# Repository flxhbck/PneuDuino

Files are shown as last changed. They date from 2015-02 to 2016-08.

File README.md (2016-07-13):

# PneuDuino

Pneuduino is a toolkit for controlling air flow and pressure to design robots that are soft, furniture that is adaptive, clothing that is intelligent, art pieces that are breathing, and many more things.

Disclaimer:
This toolkit is currently designed for workshops that we give. We are working on a more stable version for personal use. In the meantime, you are welcome to use what you find here - but be aware that is a work in progress.

For more information visit http://pneuduino.org/toolkit/

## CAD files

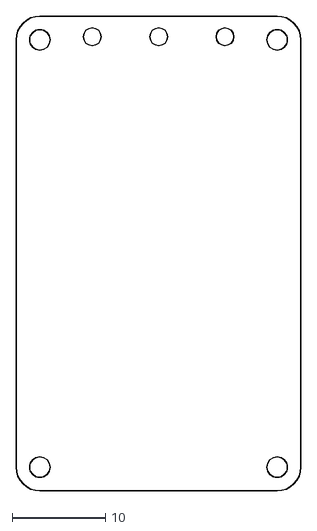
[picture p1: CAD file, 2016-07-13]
v.2/Pneumatic/pneu-slave-outline.dxf
30.5 x 50.8

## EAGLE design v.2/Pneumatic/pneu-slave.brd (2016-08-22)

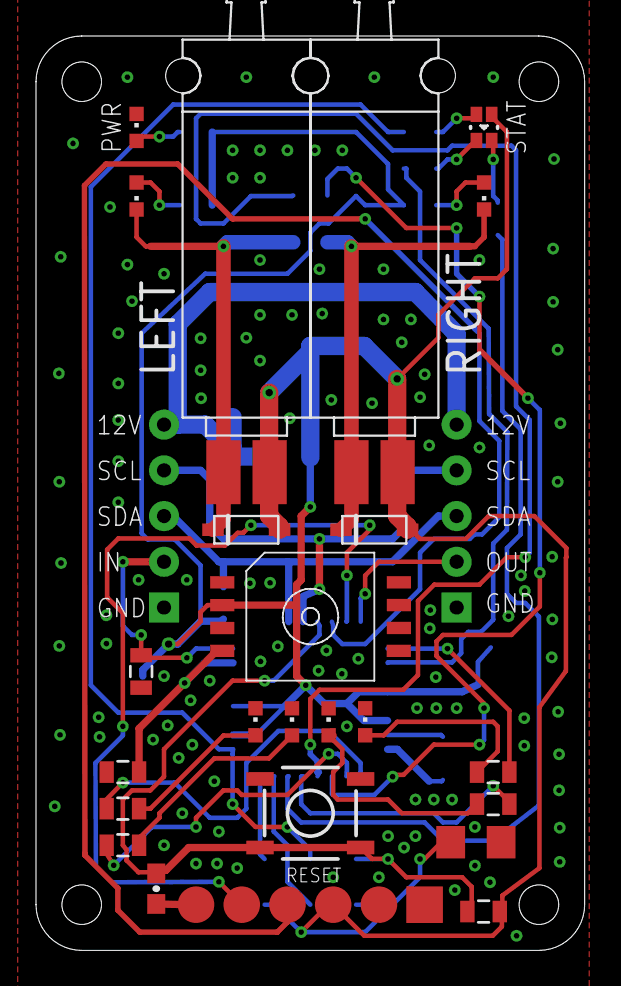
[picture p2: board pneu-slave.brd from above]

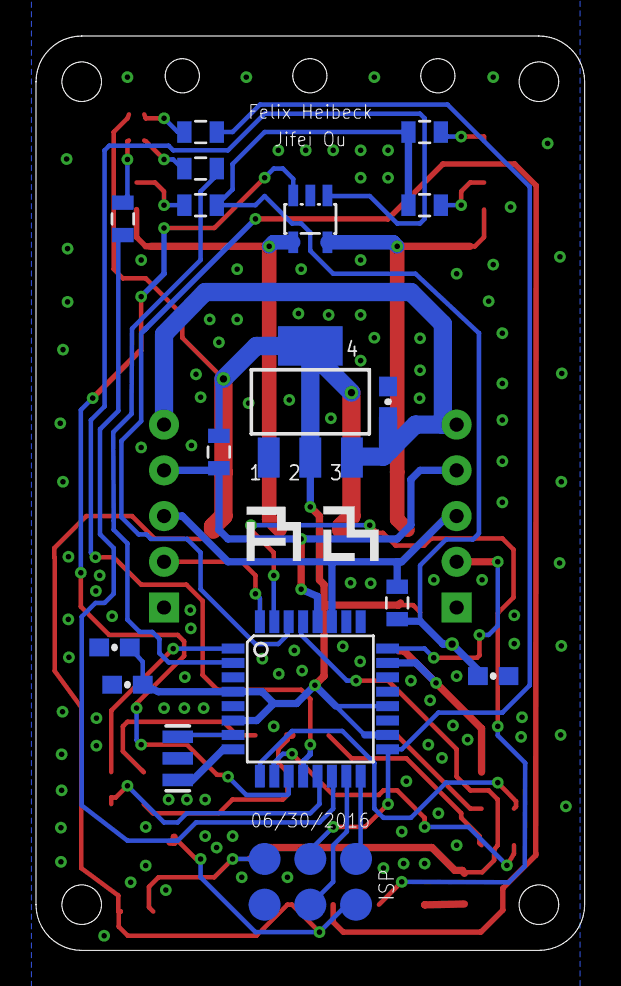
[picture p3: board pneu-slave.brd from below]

Board: 2 copper layers, 30.5 x 50.8 mm, 42 parts (17 on the bottom side), 37 nets.

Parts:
C1, C2, C5, C8, C10: 0.1uF; 0603-CAP
C4: 22uF; 1206
C7: 470pF; 0805
D1, D2: SOD-123
LED_PR1, LED_PR2, LED_PR3, LED_PR4: WHITE; CHIPLED_0603
LED_PWR: RED; CHIPLED_0603
LED_STATUS: LTST-C19FD1WT; LTST
LED_V1, LED_V2: WHITE; CHIPLED_0603
Q1: 16Mhz; RESONATOR-SMD
R1, R2, R4, R7, R8, R9, R10, R11, R12, R13: 1k; 0805
R3: 10K; 0805
R5, R6: 4.7k; 0805
R14: 10k; 0805
S1: TAC_SWITCHSMD; TACTILE-SWITCH-SMD
U0: ATMEGA328; TQFP32-08
U1: NCP1117-5; LINEAR_SOT223
U2: MPXHZ6400
U3: QS5K2; SOT23-5L
U$10: ISP_POGO; POGO_ISP
U$11: S070V-2VALVE; S070C-2
U$12: FTDI_POGO
U$23, U$24: 1X05; 1X05_TIGHT

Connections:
+5V: C2.1, C4.1, C8.1, C10.1, D1.C, D2.C, LED_STATUS.+, R2.2, R3.1, R5.1, R6.2, R8.2, R11.2, U0.4, U0.6, U0.18, U0.20, U1.2, U1.4, U2.2, U$10.2, U$11.1-2, U$11.2-2, U$12.4
A0/PRESSURE: C7.2, U0.23, U2.4
D2/OUT: U0.32, U$23.P$4
D3: R1.2, U0.1
D4: R9.2, U0.2
D5: R7.2, U0.9
D6: R4.2, U0.10
D7: U0.11, U3.3
D8: U0.12, U3.1
D9: R10.2, U0.13
D10: R12.2, U0.14
DTR: C5.2, U$12.1
GND: C1.2, C2.2, C4.2, C7.1, C8.2, C10.2, LED_PR1.C, LED_PR2.C, LED_PR3.C, LED_PR4.C, LED_PWR.C, Q1.2, R14.1, S1.1, S1.2, U0.3, U0.5, U0.21, U1.1, U2.3, U3.2, U$10.6, U$12.5, U$12.6, U$23.P$5, U$24.P$5
IN_PORT: R14.2, U0.24, U$24.P$4
M1_VGND: D1.A, LED_V2.C, U3.4, U$11.2-1
M2_VGND: D2.A, LED_V1.C, U3.5, U$11.1-1
MISO: U0.16, U$10.1
MOSI: U0.15, U$10.4
unnamed: LED_PR2.A, R4.1
unnamed: LED_PR1.A, R7.1
unnamed: Q1.1, U0.8
unnamed: LED_PR4.A, R1.1
unnamed: LED_V2.A, R2.1
unnamed: LED_V1.A, R8.1
unnamed: Q1.3, U0.7
unnamed: LED_PR3.A, R10.1
unnamed: LED_PWR.A, R11.1
unnamed: LED_STATUS.R, R9.1
unnamed: LED_STATUS.G, R12.1
unnamed: LED_STATUS.B, R13.1
RESET: C5.1, R3.2, S1.3, S1.4, U0.29, U$10.5
RX: U0.30, U$12.3
SCK: R13.2, U0.17, U$10.3
SCL: R6.1, U0.28, U$23.P$3, U$24.P$3
SDA: R5.2, U0.27, U$23.P$2, U$24.P$2
TX: U0.31, U$12.2
VIN: C1.1, U1.3, U$23.P$1, U$24.P$1

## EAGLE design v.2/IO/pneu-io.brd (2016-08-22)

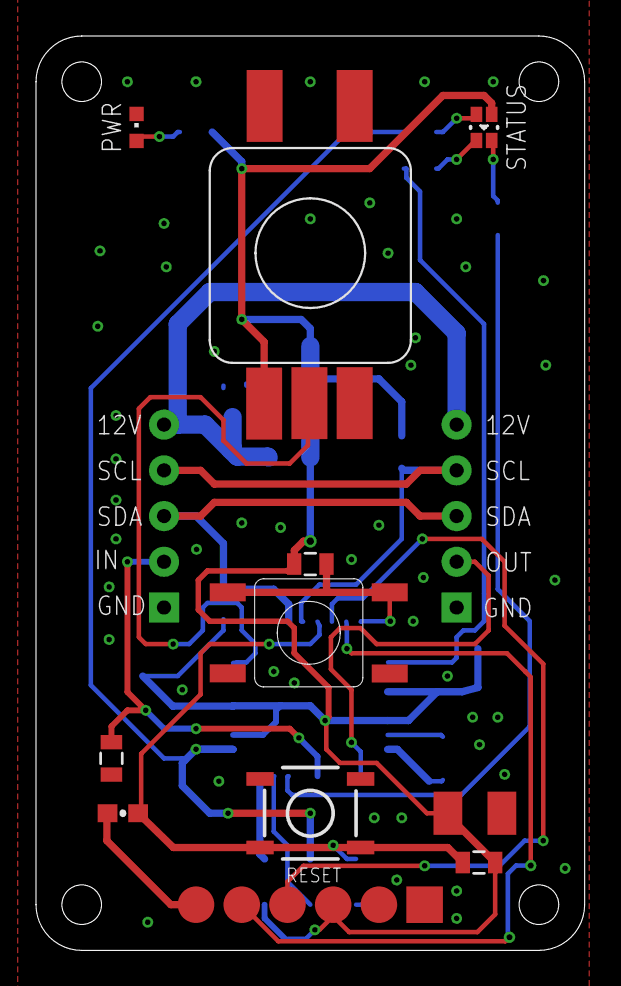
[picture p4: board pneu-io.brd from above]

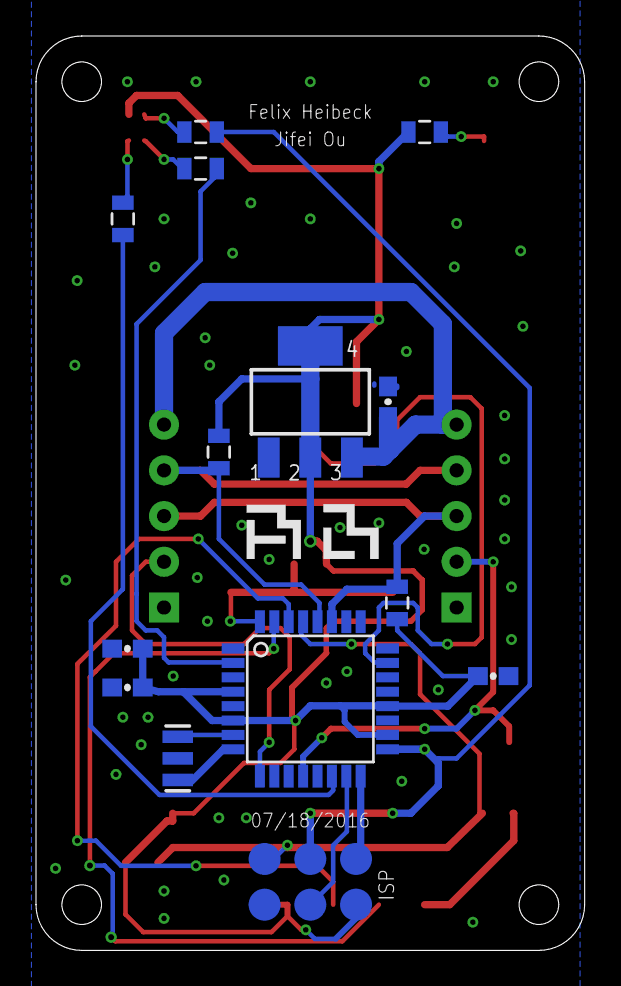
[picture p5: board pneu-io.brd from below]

Board: 2 copper layers, 30.5 x 50.8 mm, 27 parts (14 on the bottom side), 24 nets.

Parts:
C1, C2, C5, C8, C10: 0.1uF; 0603-CAP
C3: 22uF; SMC_B
IC3: ATMEGA328; TQFP32-08
PWR: CHIPLED_0603
Q1: 16Mhz; RESONATOR-SMD
R1, R3: 10K; 0805
R5, R6: 4.7k; 0805
R9, R11, R12, R13: 1k; 0805
R14: 10k; 0805
S1: TAC_SWITCHSMD; TACTILE-SWITCH-SMD
U2: NCP1117-5; LINEAR_SOT223
U$1: RS-014R05; SWITCH-11MM
U$2: PRS11S
U$10: ISP_POGO; POGO_ISP
U$12: FTDI_POGO
U$21: LTST-C19FD1WT; LTST
U$24, U$27: 1X05; 1X05_TIGHT

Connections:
+5V: C2.1, C3.+, C8.1, C10.1, IC3.4, IC3.6, IC3.18, IC3.20, R1.1, R3.1, R5.1, R6.2, R11.2, U2.2, U2.4, U$2.1, U$10.2, U$12.4, U$21.+
A0/POT: IC3.23, U$2.2
D2/BTN: IC3.32, R1.2, U$1.A, U$1.H
D4: IC3.2, R9.2
D5/OUT: IC3.9, U$27.P$4
D8: IC3.12, R14.2, U$24.P$4
D10: IC3.14, R12.2
DTR: C5.2, U$12.1
GND: C1.2, C2.2, C3.-, C8.2, C10.2, IC3.3, IC3.5, IC3.21, PWR.C, Q1.2, R14.1, S1.1, S1.2, U2.1, U$1.B, U$1.D, U$2.3, U$10.6, U$12.5, U$12.6, U$24.P$5, U$27.P$5
MISO: IC3.16, U$10.1
MOSI: IC3.15, U$10.4
unnamed: IC3.8, Q1.1
unnamed: IC3.7, Q1.3
unnamed: PWR.A, R11.1
unnamed: R9.1, U$21.R
unnamed: R12.1, U$21.G
unnamed: R13.1, U$21.B
RESET: C5.1, IC3.29, R3.2, S1.3, S1.4, U$10.5
RX: IC3.30, U$12.3
SCK: IC3.17, R13.2, U$10.3
SCL: IC3.28, R6.1, U$24.P$3, U$27.P$3
SDA: IC3.27, R5.2, U$24.P$2, U$27.P$2
TX: IC3.31, U$12.2
VIN: C1.1, U2.3, U$24.P$1, U$27.P$1

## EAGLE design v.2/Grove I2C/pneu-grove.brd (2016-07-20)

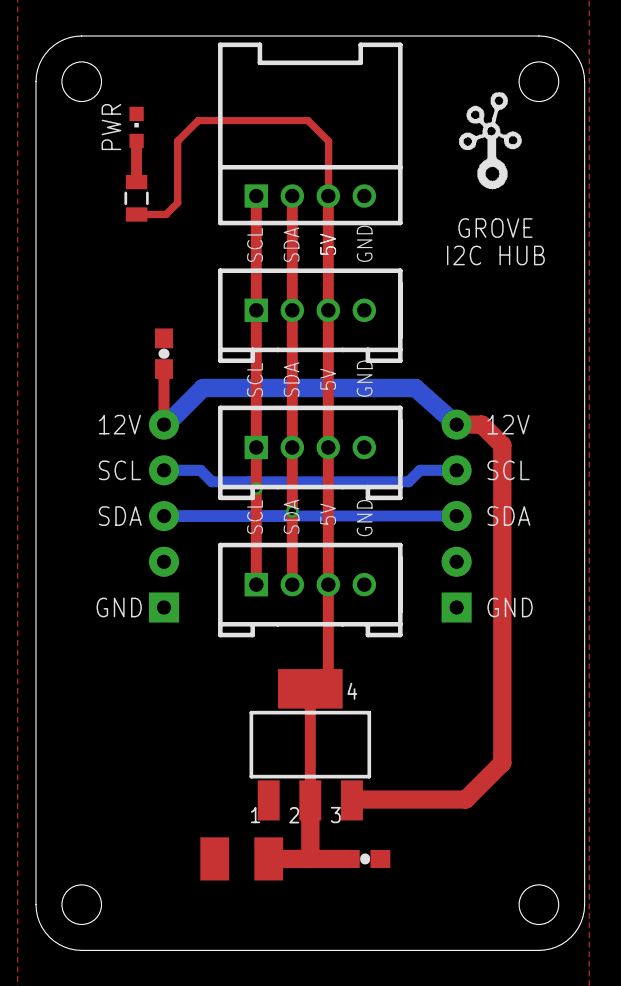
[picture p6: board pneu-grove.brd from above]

Board: 2 copper layers, 30.5 x 50.8 mm, 13 parts (0 on the bottom side), 6 nets.

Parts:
C1, C2: 0.1uF; 0603-CAP
C3: 22uF; SMC_B
J1, J4, J5: TWIG-2.0-DIP; 2.0_1X4
J12: A3; 4P-2.0-90D
PWR: CHIPLED_0603
R11: 1k; 0805
U2: NCP1117-5; LINEAR_SOT223
U$1: TWIGLOGOTWIGLOGO_SMALL; TWIGLOGO_SMALL
U$23, U$24: 1X05; 1X05_TIGHT

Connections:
+5V: C2.1, C3.+, J1.3, J4.3, J5.3, J12.3, R11.2, U2.2, U2.4
GND: C1.2, C2.2, C3.-, J1.4, J4.4, J5.4, J12.4, PWR.C, U2.1, U$23.P$5, U$24.P$5
unnamed: PWR.A, R11.1
SCL: J1.1, J4.1, J5.1, J12.1, U$23.P$3, U$24.P$3
SDA: J1.2, J4.2, J5.2, J12.2, U$23.P$2, U$24.P$2
VIN: C1.1, U2.3, U$23.P$1, U$24.P$1

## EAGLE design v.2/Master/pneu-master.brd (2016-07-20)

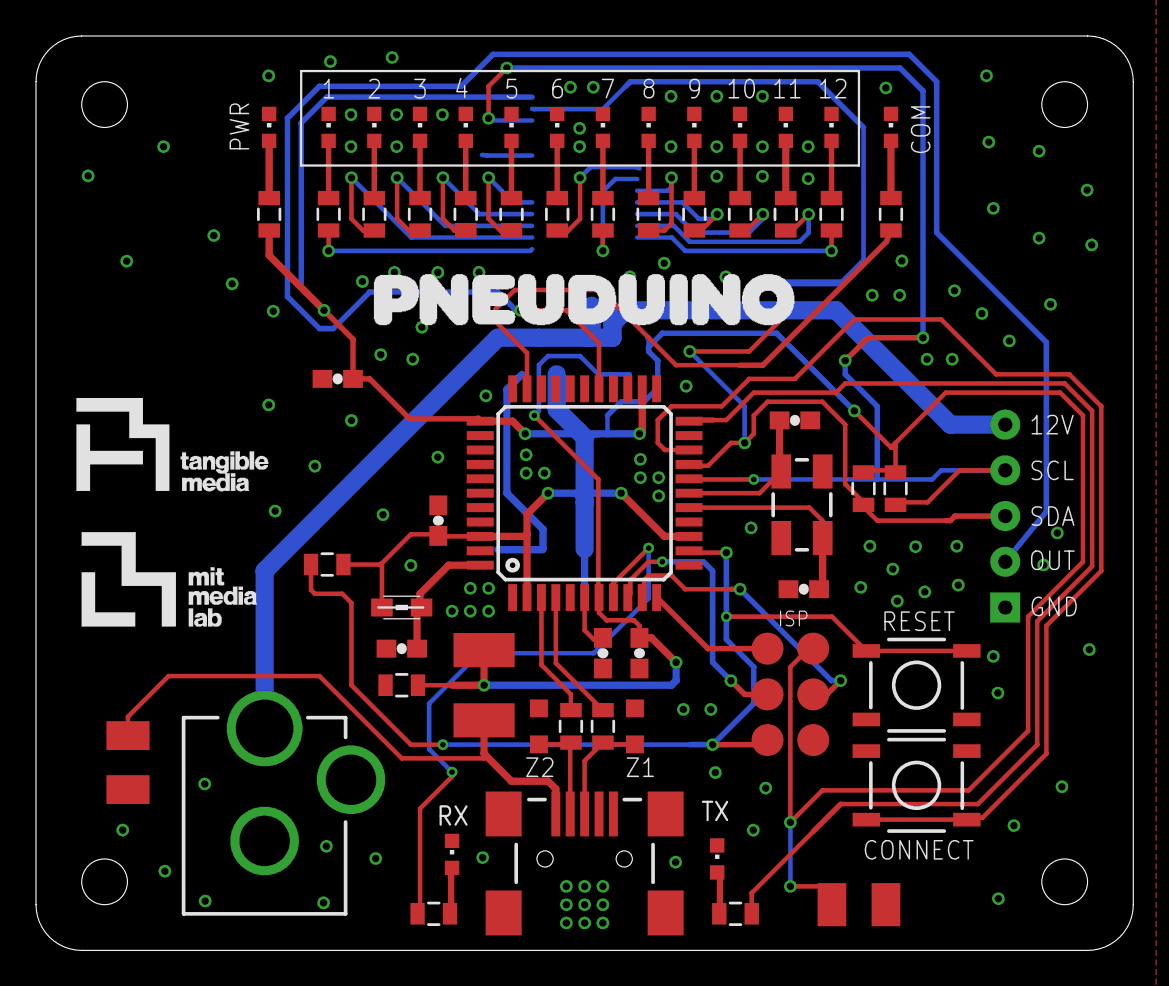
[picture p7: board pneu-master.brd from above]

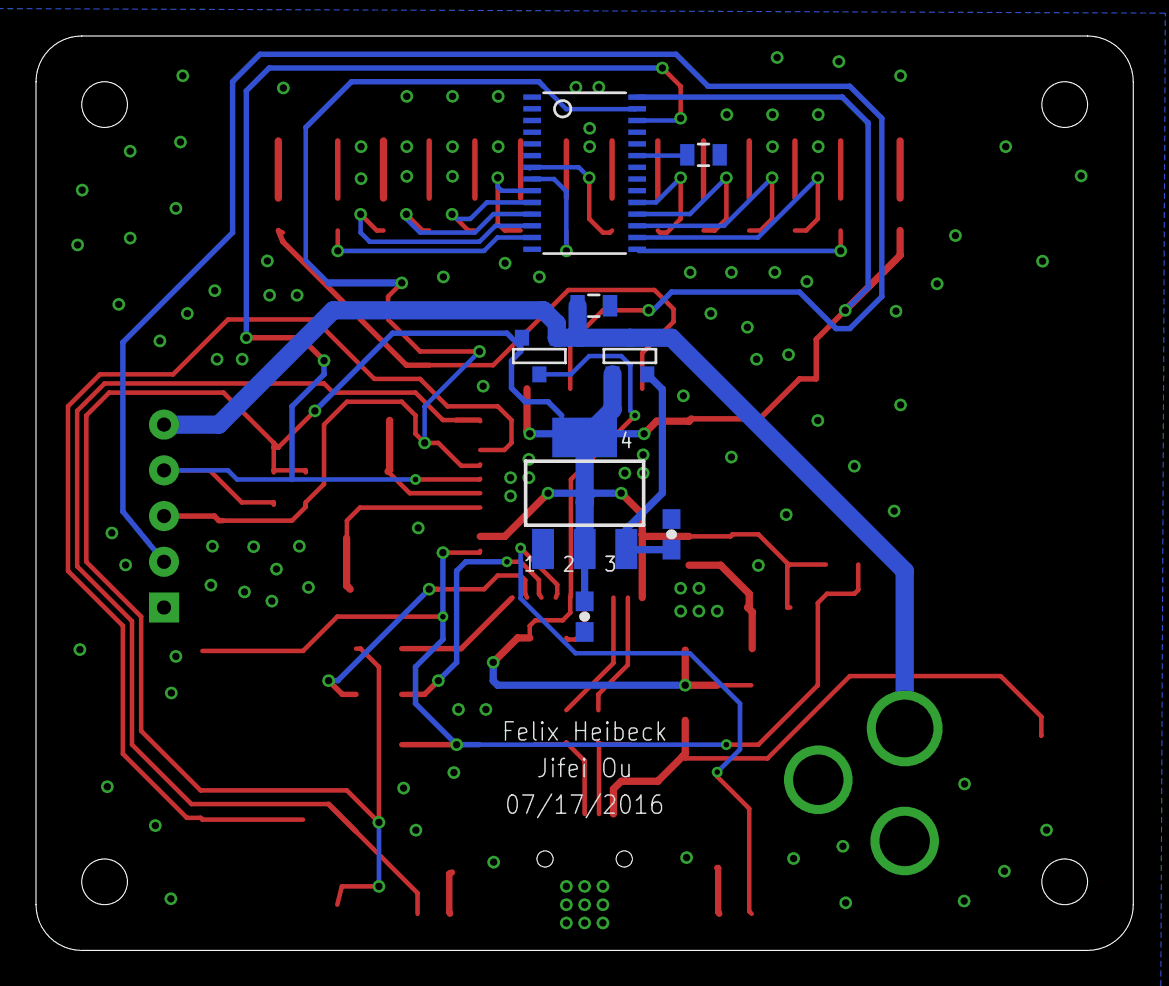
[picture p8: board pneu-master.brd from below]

Board: 2 copper layers, 61.0 x 50.8 mm, 67 parts (8 on the bottom side), 54 nets.

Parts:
1, 2, 3, 4, 5, 6, 7, 8, 9, 10, 11, 12: CHIPLED_0603
C1, C2, C6, C8, C10: 0.1uF; 0603-CAP
C3, C14: 22uF; SMC_B
C4, C7: 1uF; 0603-CAP
C16, C17: 22pF; 0603-CAP
CN1: DCJACK_2MM_PTH
COM: CHIPLED_0603
F1: MF-MSMF050-2 500mA; L1812
L1: MH2029-300Y; 0805
PWR: CHIPLED_0603
R1, R4: 22; 0805
R2, R3, R9, R12: 10K; 0805
R5, R6: opt; 0805
R10, R11, R13, R14, R15, R16, R17, R18, R19, R20, R21, R22, R23, R24, R25, R26: 1k; 0805
RX: CHIPLED_0603
S1, S2: TAC_SWITCHSMD; TACTILE-SWITCH-SMD
T1: FDN340P/PMV48XP; SOT-23
T2: PMV48XP; SOT-23
TX: CHIPLED_0603
U1: TSSOP28
U2: NCP1117-5; LINEAR_SOT223
U$3: USB-MINIB-5PIN; USB-MINIB
U$4: ATMEGA32U4-AU; TQFP44
U$10: ISP_POGO; POGO_ISP
U$14: 1X05; 1X05_TIGHT
Y2: 16MHz; CRYSTAL-SMD-5X3
Z1, Z2: CG0603MLC-05E; CT/CN0603

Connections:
+5V: C2.1, C3.+, C8.1, C10.1, L1.1, R3.1, R5.1, R6.2, R11.2, T1.2, T2.3, U1.28, U2.2, U2.4, U$4.2, U$4.14, U$4.24, U$4.34, U$4.42, U$10.2
+VIN: C1.1, T2.2, U2.3
BTN: S2.1, S2.2, U$4.20
D13: R10.2, U$4.32
D+: R4.1, U$3.D+, Z1.1
D-: R1.1, U$3.D-, Z2.1
DATA_OUT: U$4.27, U$14.P$4
GND: 1.C, 2.C, 3.C, 4.C, 5.C, 6.C, 7.C, 8.C, 9.C, 10.C, 11.C, 12.C, C1.2, C2.2, C3.-, C4.1, C6.2, C7.2, C8.2, C10.2, C14.-, C16.2, C17.2, CN1.GND, COM.C, PWR.C, R2.1, R9.1, R12.2, RX.C, S1.1, S1.2, S2.3, S2.4, TX.C, U1.1, U1.2, U1.3, U1.4, U1.5, U1.14, U1.24, U1.25, U2.1, U$3.GND, U$3.MTN1, U$3.MTN2, U$3.MTN3, U$3.MTN4, U$4.5, U$4.15, U$4.23, U$4.33, U$4.35, U$4.43, U$10.6, U$14.P$5, Z1.2, Z2.2
LED1: R13.2, U1.15
LED2: R14.2, U1.16
LED3: R15.2, U1.17
LED4: R16.2, U1.18
LED5: R17.2, U1.19
LED6: R18.2, U1.7
LED7: R19.2, U1.8
LED8: R20.2, U1.9
LED9: R21.2, U1.10
LED10: R22.2, U1.11
LED11: R25.2, U1.12
LED12: R26.2, U1.13
MISO: U$4.11, U$10.1
MOSI: U$4.10, U$10.4
unnamed: C16.1, U$4.17, Y2.3
unnamed: C17.1, U$4.16, Y2.1
unnamed: C7.1, U$4.6
unnamed: C4.2, L1.2, U$4.44
unnamed: R23.1, RX.A
unnamed: R24.1, TX.A
unnamed: COM.A, R10.1
unnamed: PWR.A, R11.1
unnamed: R12.1, U1.23
unnamed: 1.A, R13.1
unnamed: 2.A, R14.1
unnamed: 3.A, R15.1
unnamed: 4.A, R16.1
unnamed: 5.A, R17.1
unnamed: 6.A, R18.1
unnamed: 7.A, R19.1
unnamed: 8.A, R20.1
unnamed: 9.A, R21.1
unnamed: 10.A, R22.1
unnamed: 11.A, R25.1
unnamed: 12.A, R26.1
RD+: R4.2, U$4.4
RD-: R1.2, U$4.3
RESET: R3.2, S1.3, S1.4, U$4.13, U$10.5
RXLED: R23.2, U$4.8
SCK: U$4.9, U$10.3
SCL: R6.1, U1.26, U$4.18, U$14.P$3
SDA: R5.2, U1.27, U$4.19, U$14.P$2
TXLED: R24.2, U$4.22
VIN: CN1.PWR, R9.2, T1.3, T2.1, U$14.P$1
VUSB: C6.1, F1.2, R2.2, T1.1, U$4.7
VUSBD: C14.+, F1.1, U$3.VBUS

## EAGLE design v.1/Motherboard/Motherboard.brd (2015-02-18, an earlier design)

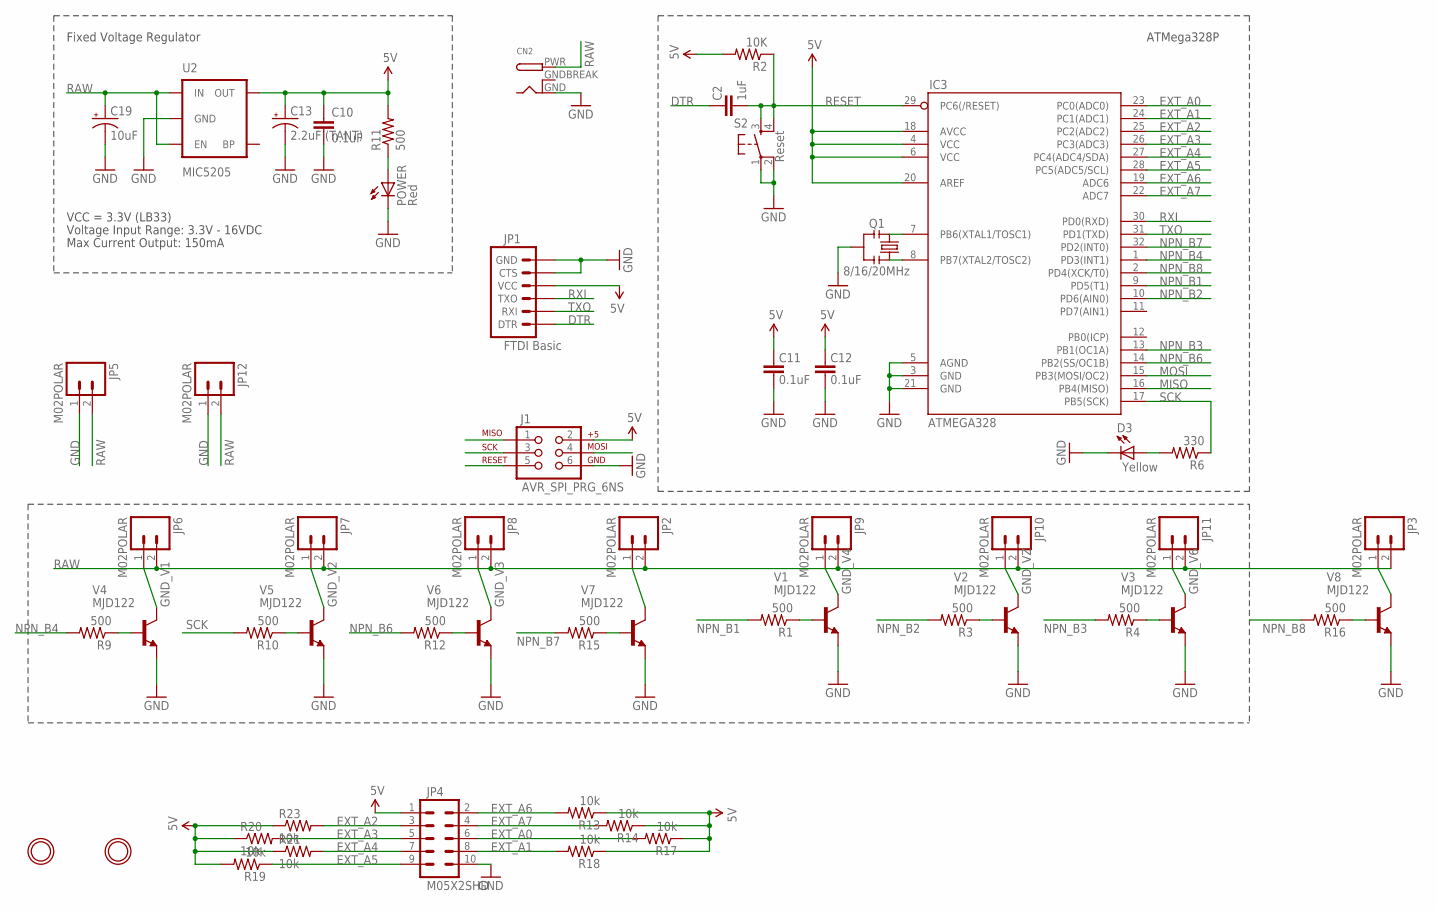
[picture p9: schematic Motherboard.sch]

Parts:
C2: 1uF; 0805
C10, C11, C12: 0.1uF; 0805
C13: 2.2uF (TANT); EIA3216
C19: 10uF; EIA3216
CN2: DCBARRELPTH; DCJACK_2MM_PTH
D3: Yellow; LED-1206
IC3: ATMEGA328; TQFP32-08
J1: AVR_SPI_PRG_6NS; 2X3-NS
JP1: FTDI Basic; 1X06
JP2, JP3, JP5, JP6, JP7, JP8, JP9, JP10, JP11, JP12: M02POLAR; MOLEX-1X2
JP4: M05X2SHD; 2X5-SHROUDED
POWER: Red; LED-1206
Q1: 8/16/20MHz; RESONATOR-SMD
R1, R3, R4, R9, R10, R11, R12, R15, R16: 500; 0805
R2: 10K; 0805
R6: 330; 0805
R13, R14, R17, R18, R19, R20, R21, R23: 10k; 0805
S2: Reset; TACTILE_SWITCH_SMD
U2: MIC5205; SOT23-5
U$1, U$2: MOUNTINGHOLE2.5; MOUNTINGHOLE_2.5_PLATED
V1, V2, V3, V4, V5, V6, V7, V8: MJD122; DPAK

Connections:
5V: C10.1, C11.2, C12.2, C13.A (+), IC3.4 (VCC), IC3.6 (VCC), IC3.18 (AVCC), IC3.20 (AREF), J1.2, JP1.4 (VCC), JP4.1, R2.2, R11.2, R13.1, R14.1, R17.1, R18.1, R19.2, R20.1, R21.1, R23.1, U2.5 (OUT)
DTR: C2.2, JP1.1 (DTR)
EXT_A0: IC3.23 (PC0(ADC0)), JP4.6, R17.2
EXT_A1: IC3.24 (PC1(ADC1)), JP4.8, R18.2
EXT_A2: IC3.25 (PC2(ADC2)), JP4.3, R23.2
EXT_A3: IC3.26 (PC3(ADC3)), JP4.5, R20.2
EXT_A4: IC3.27 (PC4(ADC4/SDA)), JP4.7, R21.2
EXT_A5: IC3.28 (PC5(ADC5/SCL)), JP4.9, R19.1
EXT_A6: IC3.19 (ADC6), JP4.2, R13.2
EXT_A7: IC3.22 (ADC7), JP4.4, R14.2
GND: C10.2, C11.1, C12.1, C13.C (-), C19.C (-), CN2.GND, D3.C, IC3.3 (GND), IC3.5 (AGND), IC3.21 (GND), J1.6, JP1.5 (CTS), JP1.6 (GND), JP4.10, JP5.1, JP12.1, POWER.C, Q1.2, S2.1, S2.2, U2.2 (GND), V1.3 (E), V2.3 (E), V3.3 (E), V4.3 (E), V5.3 (E), V6.3 (E), V7.3 (E), V8.3 (E)
GNDBREAK: CN2.GNDBREAK
GND_V1: JP6.1, V4.4 (C)
GND_V2: JP7.1, V5.4 (C)
GND_V3: JP8.1, V6.4 (C)
GND_V4: JP9.1, V1.4 (C)
GND_V6: JP11.1, V3.4 (C)
GND_V7: JP2.1, V7.4 (C)
GND_V8: JP3.1, V8.4 (C)
GND_VZ: JP10.1, V2.4 (C)
MISO: IC3.16 (PB4(MISO)), J1.1
MOSI: IC3.15 (PB3(MOSI/OC2)), J1.4
unnamed: IC3.8 (PB7(XTAL2/TOSC2)), Q1.1
unnamed: IC3.7 (PB6(XTAL1/TOSC1)), Q1.3
unnamed: R9.1, V4.1 (B)
unnamed: R1.1, V1.1 (B)
unnamed: R10.1, V5.1 (B)
unnamed: R12.1, V6.1 (B)
unnamed: D3.A, R6.2
unnamed: R3.1, V2.1 (B)
unnamed: R4.1, V3.1 (B)
unnamed: R16.1, V8.1 (B)
unnamed: R15.1, V7.1 (B)
unnamed: POWER.A, R11.1
NPN_B1: IC3.9 (PD5(T1)), R1.2
NPN_B2: IC3.10 (PD6(AIN0)), R3.2
NPN_B3: IC3.13 (PB1(OC1A)), R4.2
NPN_B4: IC3.1 (PD3(INT1)), R9.2
NPN_B6: IC3.14 (PB2(SS/OC1B)), R12.2
NPN_B7: IC3.32 (PD2(INT0)), R15.2
NPN_B8: IC3.2 (PD4(XCK/T0)), R16.2
RAW: C19.A (+), CN2.PWR, JP2.2, JP3.2, JP5.2, JP6.2, JP7.2, JP8.2, JP9.2, JP10.2, JP11.2, JP12.2, U2.1 (IN), U2.3 (EN)
RESET: C2.1, IC3.29 (PC6(/RESET)), J1.5, R2.1, S2.3, S2.4
RXI: IC3.30 (PD0(RXD)), JP1.3 (TXO)
SCK: IC3.17 (PB5(SCK)), J1.3, R6.1, R10.2
TXO: IC3.31 (PD1(TXD)), JP1.2 (RXI)

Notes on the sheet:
Max Current Output: 150mA
VCC = 3.3V (LB33)
Voltage Input Range: 3.3V - 16VDC
Fixed Voltage Regulator
ATMega328P

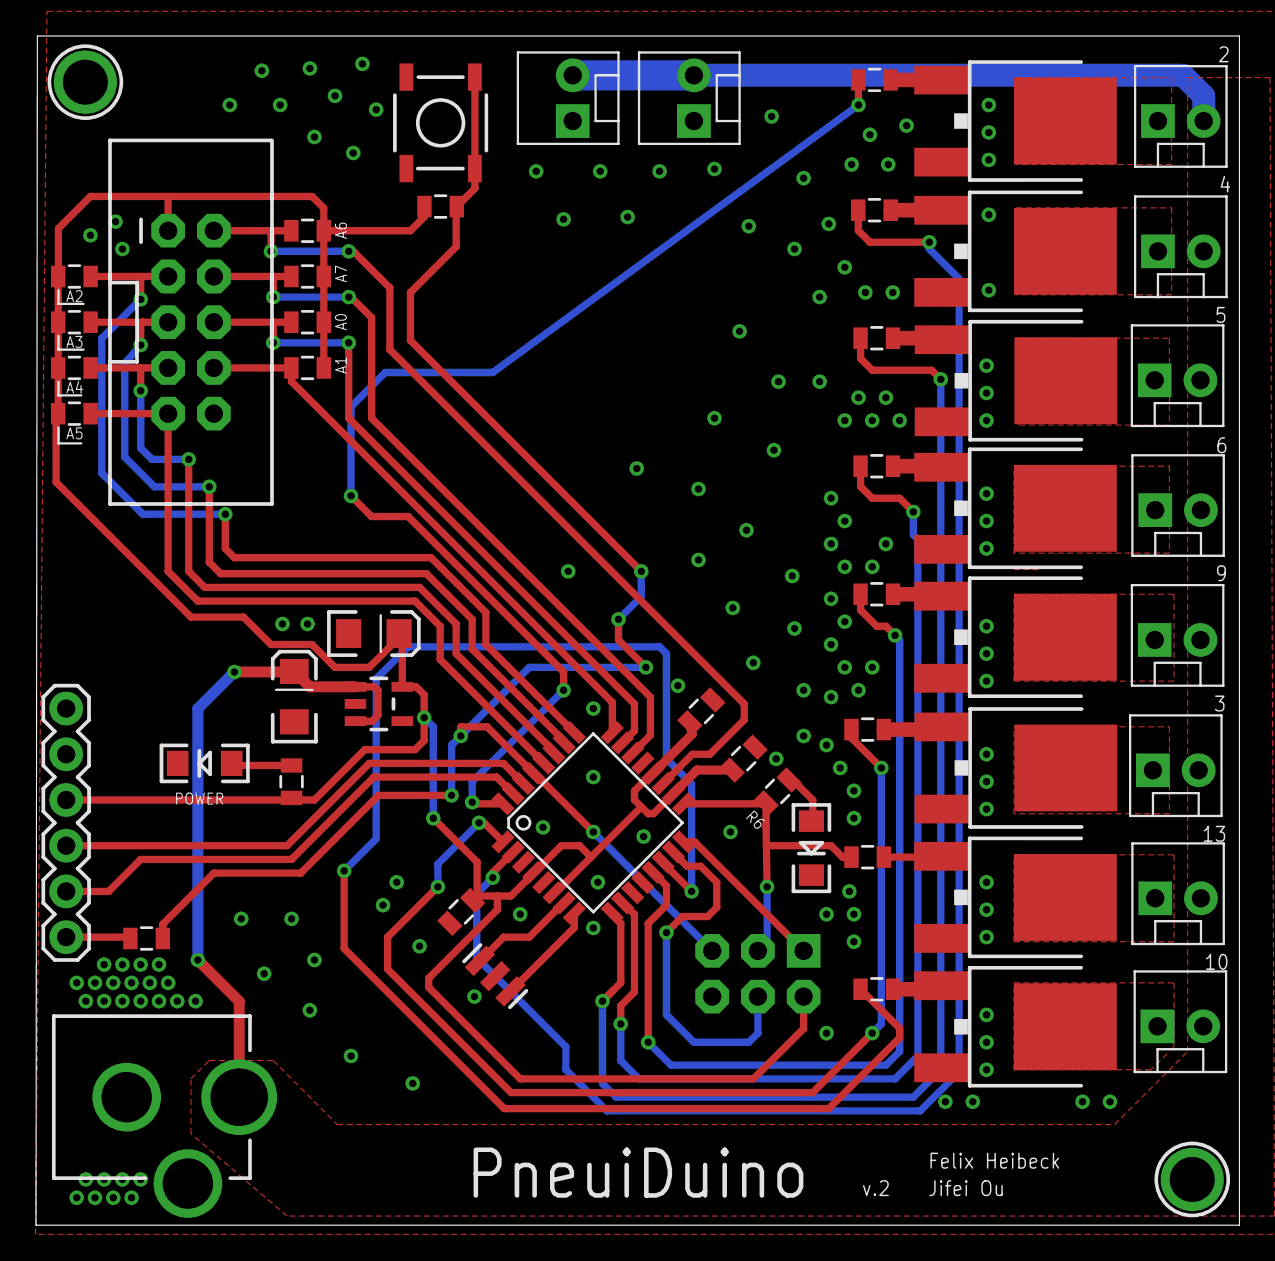
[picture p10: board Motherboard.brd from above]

Board: 2 copper layers, 66.9 x 66.1 mm, 55 parts (0 on the bottom side), 45 nets.

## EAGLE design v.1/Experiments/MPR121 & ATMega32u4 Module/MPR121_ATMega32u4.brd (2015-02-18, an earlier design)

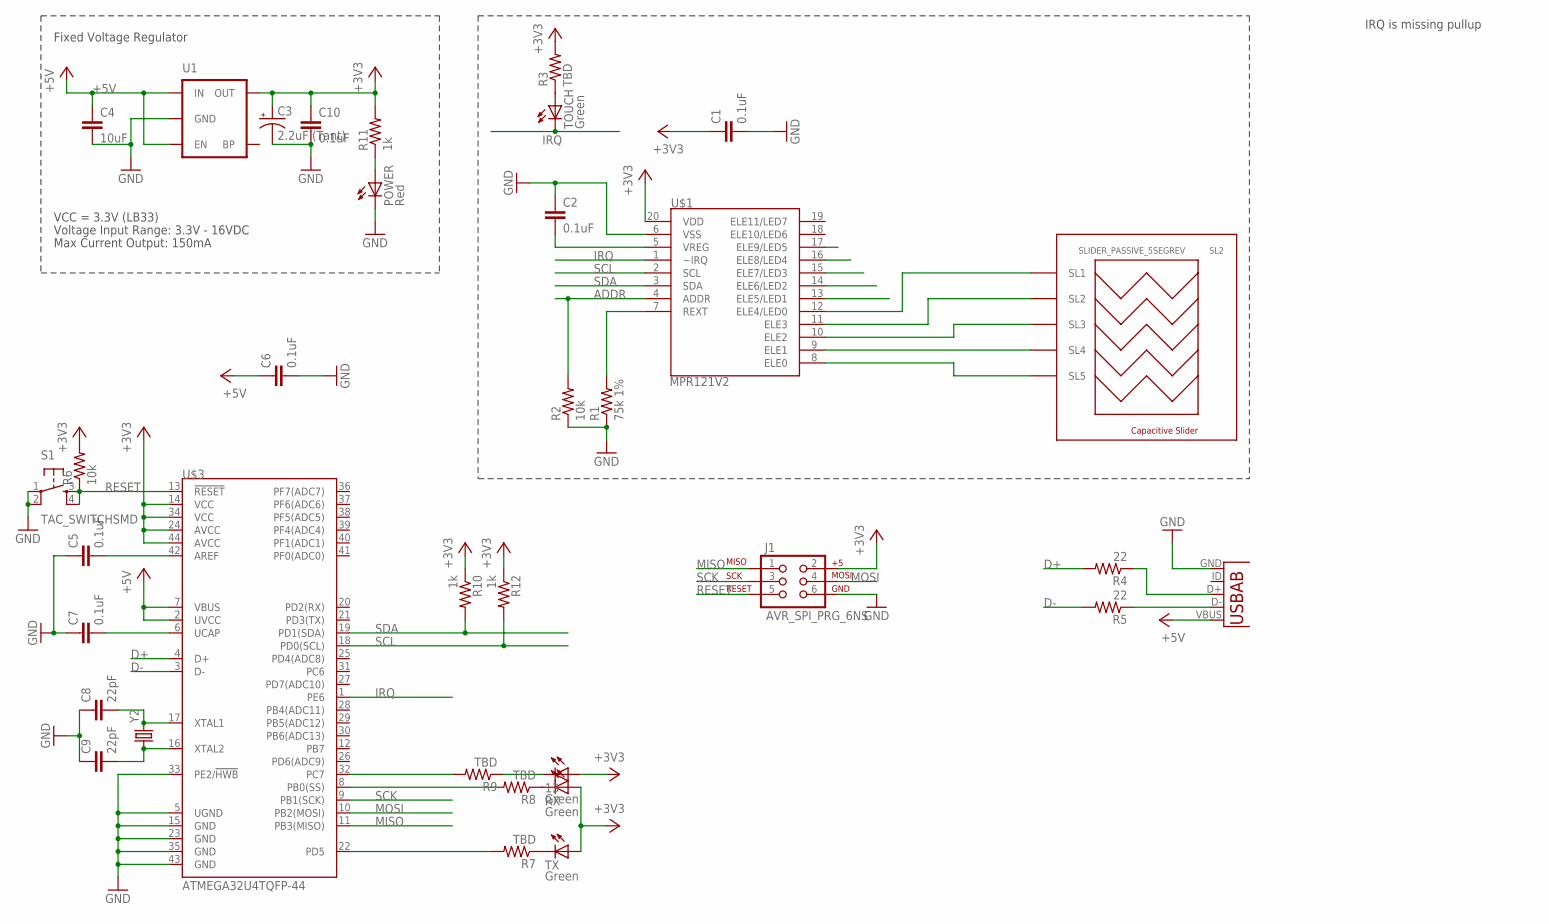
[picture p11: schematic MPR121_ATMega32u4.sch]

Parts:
13: Green; LED-1206
C1, C2, C5, C6, C7, C10: 0.1uF; 0805
C3: 2.2uF (Tant); EIA3216
C4: 10uF; 1206
C8, C9: 22pF; 0805
J1: AVR_SPI_PRG_6NS; 2X3-NS
POWER: Red; LED-1206
R1: 75k 1%; 0805
R2, R6: 10k; 0805
R3, R7, R8, R9: TBD; 0805
R4, R5: 22; 0805
R10, R11, R12: 1k; 0805
RX: Green; LED-1206
S1: TAC_SWITCHSMD; TACTILE-SWITCH-SMD
SL2: SLIDER_PASSIVE_5SEGREV; SLIDER_PASSIVE_5SEG_12MM_REV
TOUCH: Green; LED-1206
TX: Green; LED-1206
U1: MIC52053.3V; SOT23-5
U2: USB-AB; USB-AB-MICRO-SMD
U$1: MPR121V2; QFN-20-0.4MM-V2
U$3: ATMEGA32U4TQFP-44; TQFP44
Y2: CRYSTAL5X3; CRYSTAL-SMD-5X3

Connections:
+3V3: 13.A, C1.1, C3.A (+), C10.1, J1.2, R3.2, R6.2, R10.1, R11.2, R12.1, RX.A, TX.A, U1.5 (OUT), U$1.20 (VDD), U$3.14 (VCC), U$3.24 (AVCC), U$3.34 (VCC), U$3.44 (AVCC)
+5V: C4.1, C6.1, U1.1 (IN), U1.3 (EN), U2.VBUS, U$3.2 (UVCC), U$3.7 (VBUS)
ADDR: R2.2, U$1.4 (ADDR)
D+: R4.2, U$3.4 (D+)
D-: R5.2, U$3.3 (D-)
GND: C1.2, C2.1, C3.C (-), C4.2, C5.1, C6.2, C7.1, C8.1, C9.1, C10.2, J1.6, POWER.C, R1.1, R2.1, S1.1, S1.2, U1.2 (GND), U2.GND, U$1.6 (VSS), U$3.5 (UGND), U$3.15 (GND), U$3.23 (GND), U$3.33 (PE2/!HWB), U$3.35 (GND), U$3.43 (GND)
IRQ: TOUCH.C, U$1.1 (~IRQ), U$3.1 (PE6)
MISO: J1.1, U$3.11 (PB3(MISO))
MOSI: J1.4, U$3.10 (PB2(MOSI))
unnamed: C2.2, U$1.5 (VREG)
unnamed: R1.2, U$1.7 (REXT)
unnamed: SL2.SL5, U$1.8 (ELE0)
unnamed: SL2.SL4, U$1.9 (ELE1)
unnamed: SL2.SL3, U$1.10 (ELE2)
unnamed: SL2.SL2, U$1.11 (ELE3)
unnamed: SL2.SL1, U$1.12 (ELE4/LED0)
unnamed: R3.1, TOUCH.A
unnamed: C7.2, U$3.6 (UCAP)
unnamed: C9.2, U$3.16 (XTAL2), Y2.1
unnamed: C8.2, U$3.17 (XTAL1), Y2.3 (2)
unnamed: R5.1, U2.D-
unnamed: R4.1, U2.D+
unnamed: R8.2, U$3.8 (PB0(SS))
unnamed: R7.2, U$3.22 (PD5)
unnamed: R8.1, RX.C
unnamed: R7.1, TX.C
unnamed: C5.2, U$3.42 (AREF)
unnamed: 13.C, R9.1
unnamed: R9.2, U$3.32 (PC7)
unnamed: POWER.A, R11.1
RESET: J1.5, R6.1, S1.3, S1.4, U$3.13 (!RESET)
SCK: J1.3, U$3.9 (PB1(SCK))
SCL: R12.2, U$1.2 (SCL), U$3.18 (PD0(SCL))
SDA: R10.2, U$1.3 (SDA), U$3.19 (PD1(SDA))

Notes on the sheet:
Max Current Output: 150mA
VCC = 3.3V (LB33)
Voltage Input Range: 3.3V - 16VDC
Fixed Voltage Regulator
IRQ is missing pullup

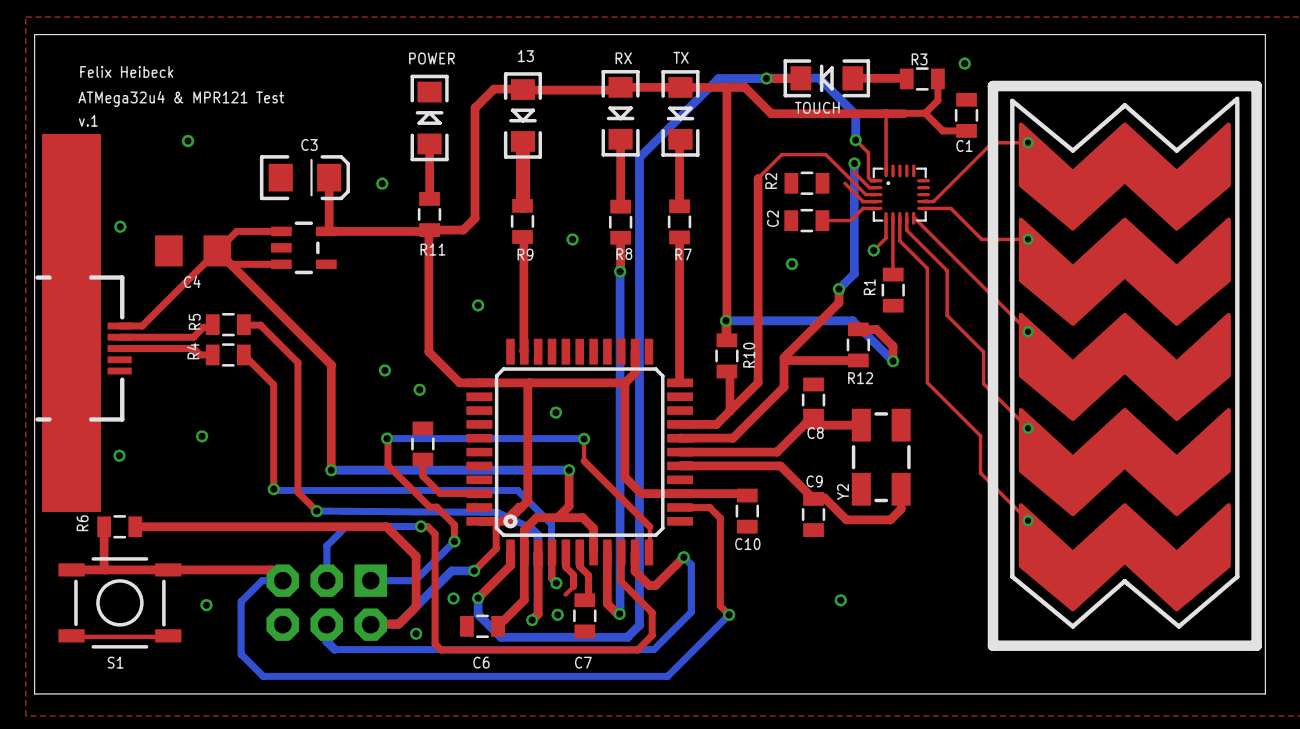
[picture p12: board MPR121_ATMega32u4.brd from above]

Board: 2 copper layers, 71.1 x 38.1 mm, 35 parts (0 on the bottom side), 34 nets.

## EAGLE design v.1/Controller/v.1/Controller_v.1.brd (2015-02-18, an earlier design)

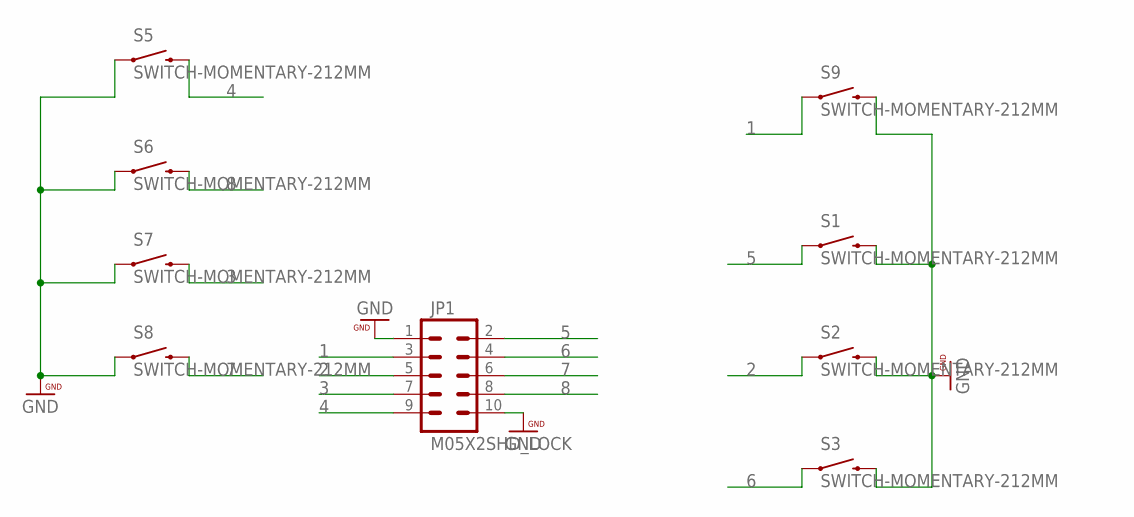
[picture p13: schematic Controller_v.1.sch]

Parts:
JP1: M05X2SHD_LOCK; 2X5-SHROUDED_LOCK
S1, S2, S3, S5, S6, S7, S8, S9: SWITCH-MOMENTARY-212MM; TACTILE-PTH-12MM

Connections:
1: JP1.3, S9.1
2: JP1.5, S2.1
3: JP1.7, S7.3 (2)
4: JP1.9, S5.3 (2)
5: JP1.2, S1.1
6: JP1.4, S3.1
7: JP1.6, S8.3 (2)
8: JP1.8, S6.3 (2)
GND: JP1.1, JP1.10, S1.3 (2), S2.3 (2), S3.3 (2), S5.1, S6.1, S7.1, S8.1, S9.3 (2)


Board: 2 copper layers, 100.0 x 42.2 mm, 9 parts (1 on the bottom side), 9 nets.

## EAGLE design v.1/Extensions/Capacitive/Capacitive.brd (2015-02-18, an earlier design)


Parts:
1, 2, 3, 4, 5, 6, 7, 8: LEDCHIPLED_0805; CHIPLED_0805
C1, C2: 0.1uF; 0805
IC1, IC2: AT42QT1070; SO14
JP4: M05X2SHD; 2X5-SHROUDED
R1, R2, R3, R4, R5, R6, R7, R8: 470; 0805
R9, R10, R11, R12, R13, R14, R15, R16: 10k; 0805
U$1, U$2, U$3, U$4, U$5, U$6, U$7, U$8: ALLIGATOR_CONN; 3MM_ALLIGATOR
U$9, U$10, U$11, U$12: MOUNTINGHOLE2.0; MOUNTINGHOLE_2.0_PLATED

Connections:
5V: C1.1, C2.1, IC1.1 (VDD), IC1.2 (MODE), IC2.1 (VDD), IC2.2 (MODE), JP4.1, R1.1, R2.1, R3.1, R4.1, R5.1, R6.1, R7.1, R8.1
07: JP4.2
GND: C1.2, C2.2, IC1.14 (VSS), IC2.14 (VSS), JP4.10
unnamed: 1.A, R1.2
unnamed: 3.A, R2.2
unnamed: 2.A, R3.2
unnamed: 4.A, R4.2
unnamed: 8.A, R5.2
unnamed: 7.A, R6.2
unnamed: 6.A, R7.2
unnamed: 5.A, R8.2
unnamed: IC1.13 (G_IN), R9.2
unnamed: IC1.12 (IN1), R10.2
unnamed: IC1.11 (IN2), R11.2
unnamed: IC1.10 (IN3), R12.2
unnamed: R12.1, U$4.ALLIGATOR, U$4.ALLIGATOR1
unnamed: R11.1, U$3.ALLIGATOR, U$3.ALLIGATOR1
unnamed: R10.1, U$2.ALLIGATOR, U$2.ALLIGATOR1
unnamed: R9.1, U$1.ALLIGATOR, U$1.ALLIGATOR1
unnamed: IC2.13 (G_IN), R13.2
unnamed: IC2.12 (IN1), R14.2
unnamed: IC2.11 (IN2), R15.2
unnamed: IC2.10 (IN3), R16.2
unnamed: R14.1, U$6.ALLIGATOR, U$6.ALLIGATOR1
unnamed: R15.1, U$7.ALLIGATOR, U$7.ALLIGATOR1
unnamed: R16.1, U$8.ALLIGATOR, U$8.ALLIGATOR1
unnamed: R13.1, U$5.ALLIGATOR, U$5.ALLIGATOR1
O0: 1.C, IC1.3 (G_OUT), JP4.3
O1: 2.C, IC1.8 (OUT1), JP4.5
O2: 3.C, IC1.7 (OUT2), JP4.7
O3: 4.C, IC1.6 (OUT3), JP4.9
O4: 5.C, IC2.3 (G_OUT), JP4.8
O5: 6.C, IC2.8 (OUT1), JP4.6
O6: 7.C, IC2.7 (OUT2), JP4.4
O7: 8.C, IC2.6 (OUT3)

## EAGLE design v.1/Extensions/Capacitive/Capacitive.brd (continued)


Board: 2 copper layers, 63.5 x 50.8 mm, 41 parts (0 on the bottom side), 34 nets.

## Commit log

2015-09-26 added arduino library
    sans IO board part.
2015-09-27 connect/reset on button press.
2015-10-10 added IO board. fixed address space.
2016-02-29 minor changes.
    [radical-pneu.brd]
2016-06-28 added 5th pin
    5th pin will allow dynamic addressing of the connected boards.
    also added holes in the corners for fixtures.
    [radical-pneu.brd, radical-pneu.sch]
2016-07-13 added dxf
    [pneu-outline.dxf]
2016-07-13 proper naming
    [pneu-grove.brd, pneu-grove.sch, pneu-io.brd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]
2016-07-20 minor changes
    getting ready for production:
    correct indicator led position on master board
    add corner drills to slave boards
    generate silk screens
    adjust edge connector distance for better fit
    [pneu-grove.brd, pneu-grove.sch, pneu-io.brd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]
2016-08-22 small updates..
    [pneu-io.brd, pneu-io.sch, pneu-master.sch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]

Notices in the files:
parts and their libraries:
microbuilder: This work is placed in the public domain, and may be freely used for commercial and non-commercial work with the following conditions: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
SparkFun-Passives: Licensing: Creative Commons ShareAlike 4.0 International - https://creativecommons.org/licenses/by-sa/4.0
